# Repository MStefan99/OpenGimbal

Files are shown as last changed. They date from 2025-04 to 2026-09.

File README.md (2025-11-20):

# OpenGimbal

## Smooth footage made hackable

**Open source gimbal you can build, tweak and extend to match all your filming needs**

Note: OpenGimbal is undergoing final preparations before the first public release. Documentation is still being written
and hardware designs are undergoing final testing and will be published shortly.

## Highlights
### Hackable
Add as many motors as you like, control them over USB or UART and mount it anywhere you like. Use it as is or integrate it into your own project.

### Ready to use
Between firmware and software, PCB designs and 3D-printable parts, everything is ready for you to go.
Built-in calibrations and checks get the headache out of the setup process.

### Small but mighty
Film for 10 hours on a single charge, enjoy 15 watts of peak power and standby time measured in years.

## Introduction

A gimbal is a device that lets you shoot smooth video by canceling out unwanted camera movements. They come in many shapes and sizes, from tiny ones with integrated cameras to heavy-duty
devices for DSLRs or film cameras, often mounted on drones or cranes.

OpenGimbal can be all of those! The philosophy behind OpenGimbal is to make every single part customizable and extensible for your own needs.
The provided designs allow you to get started with a small but powerful smartphone gimbal in a few hours, but you can always adapt them to your own needs.

OpenGimbal is not just handy for gimbals, though. Grab included designs and firmware for brushless motor controllers and make anything you want move!

## Features

- Includes everything you need to get started: PCB designs, 3D models, firmware, software and documentation.
- Film for 10 hours on a single 18650 battery or add more capacity!
- Enjoy 15 watts of peak power with the provided controller or bring your own for up to 22 watts per motor!
- Stop worrying about the battery with USB-C charging and standby time measured in years.
- Every part can be customized, left out or replaced with your own designs to fit your needs.
- Can be easily controlled by your own software or hardware over USB or UART.
- Stock or custom, just point and shoot instantly without worrying about math with the fast IK solver.
- Easily customizable firmware with ready-made drivers, simple API and extensive documentation.
- Completely open source!

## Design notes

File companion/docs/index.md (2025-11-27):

---
# https://vitepress.dev/reference/default-theme-home-page
layout: home

hero:
  name: 'OpenGimbal'
  text: 'Smooth footage made hackable'
  tagline: Open source gimbal you can build, tweak and extend to match all your filming needs
  actions:
    - theme: brand
      text: Build your own
      link: /build
    - theme: alt
      text: Learn more
      link: /intro

features:
  - title: Hackable
    details: Add as many motors as you like, control them over USB or UART and mount it anywhere you want.
  - title: Butter smooth
    details: Don't let a stutter ruin your shot with refresh rates of up to 7000Hz
  - title: Lightning fast
    details: Shoot lag-free thanks to 4ms end-to-end latency and predictive oversampling
  - title: Small but mighty
    details: Film for 10 hours on a single charge, enjoy 15 watts of peak power and standby time measured in years.
---

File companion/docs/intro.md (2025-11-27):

# Introduction

::: warning
OpenGimbal is undergoing final preparations before the first public release. Documentation is still being written
and hardware designs are undergoing final testing and will be published shortly.
:::

A gimbal is a device that lets you shoot smooth video by canceling out unwanted camera movements. They come in many shapes and sizes, from tiny ones with integrated cameras to heavy-duty
devices for DSLRs or film cameras, often mounted on drones or cranes.

OpenGimbal can be all of those! The philosophy behind OpenGimbal is to make every single part customizable and extensible for your own needs.
The provided designs allow you to get started with a small but powerful smartphone gimbal in a few hours, but you can always adapt them to your own needs.

OpenGimbal is not just handy for gimbals, though. Grab included designs and firmware for brushless motor controllers and spin anything you want!

## Features

### Hackable

You can check out, customize, remove or replace every single part of the project to fit your needs.
Control the gimbal from your own hardware and software with simple API and provided libraries.

### Fast and smooth

Enjoy low latency and high refresh rates thanks to the firmware written for the best performance.

### Small but mighty

Film for 10 hours on a single 18650 battery or add more capacity. Instantly access 15 watts of peak power.
Charge over USB-C. Don't worry about battery with standby time measured in years.

### Math? Not needed

Use a blazing-fast IK solver for default configuration or go with numeric solver for custom designs.

### All-inclusive

Find everything you need to get started fast: PCB designs, 3D models, firmware, software, API, libraries and documentation.

### Completely open source!

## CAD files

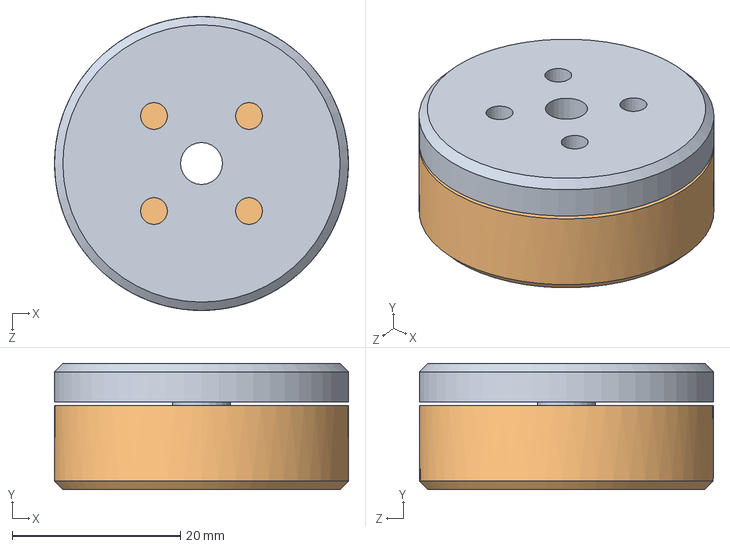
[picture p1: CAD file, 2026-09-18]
3D/Components/Motor.SLDASM
35.0 x 15.0 x 35.0 mm
Motor stator
Motor rotor

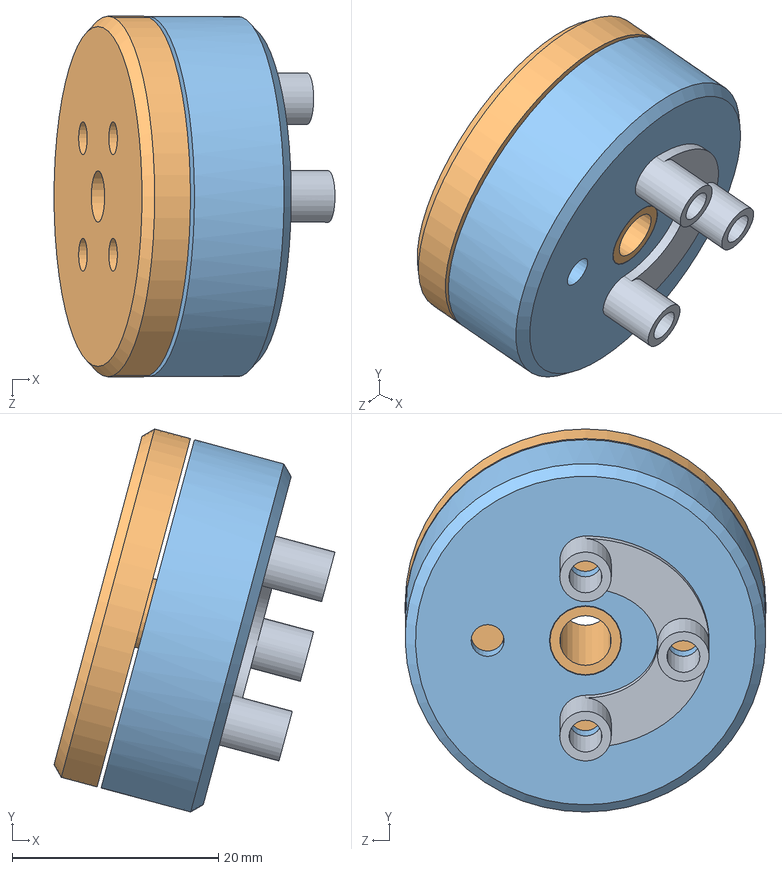
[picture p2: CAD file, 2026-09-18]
3D/Head/Motor assembly.SLDASM
27.3 x 37.2 x 35.0 mm
Motor stator
Motor rotor
Spacer

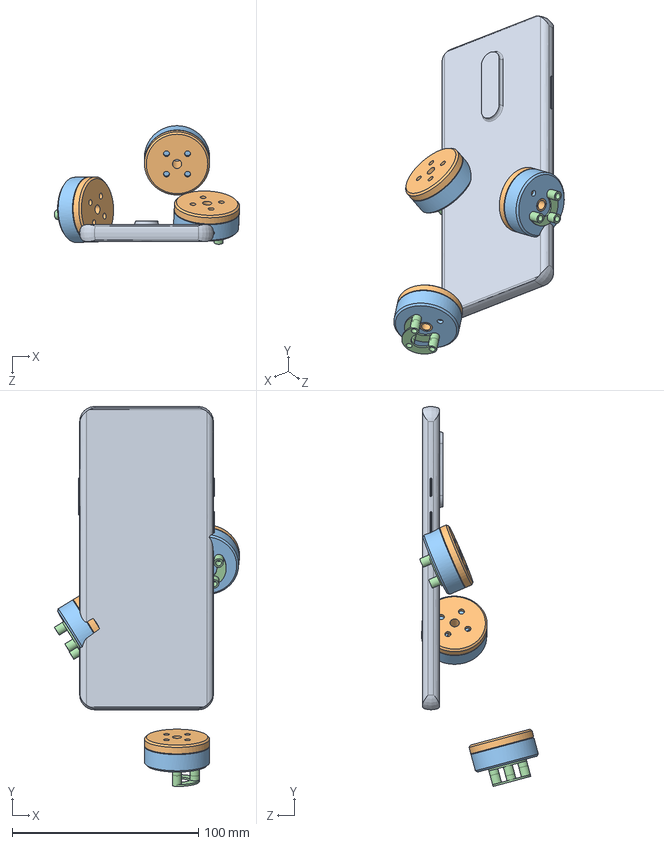
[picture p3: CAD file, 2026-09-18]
3D/Gimbal.SLDASM
99.4 x 203.9 x 63.7 mm
Spacer x 4
Motor stator x 3
Motor rotor x 3
Phone

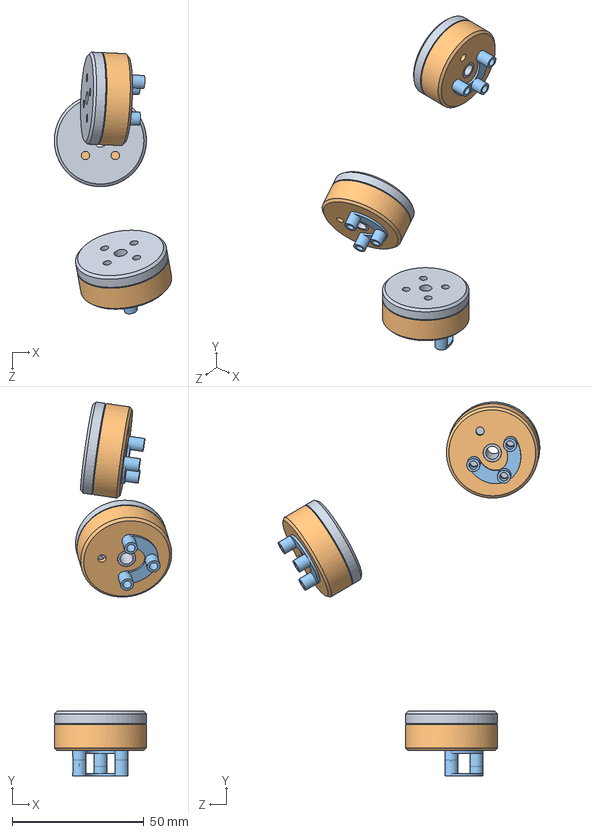
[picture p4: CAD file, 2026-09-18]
3D/Head/Head.SLDASM
44.6 x 142.0 x 99.4 mm
Spacer x 4
Motor stator x 3
Motor rotor x 3

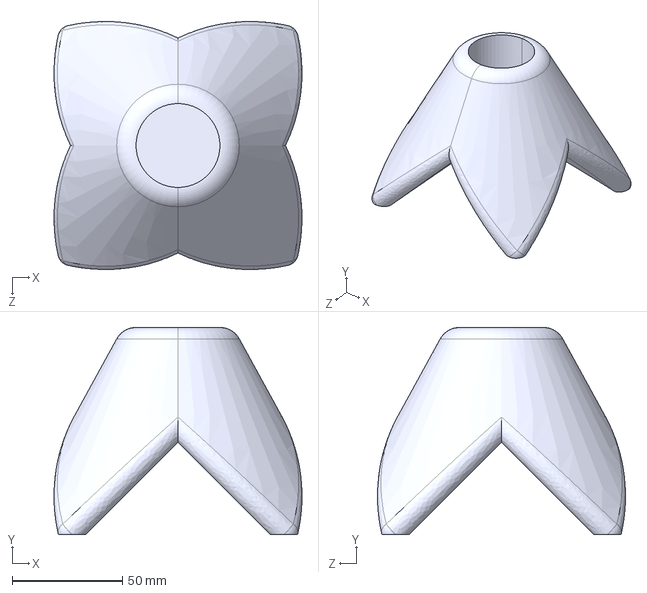
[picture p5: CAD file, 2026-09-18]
3D/Stand.STEP
112.3 x 93.9 x 112.3 mm

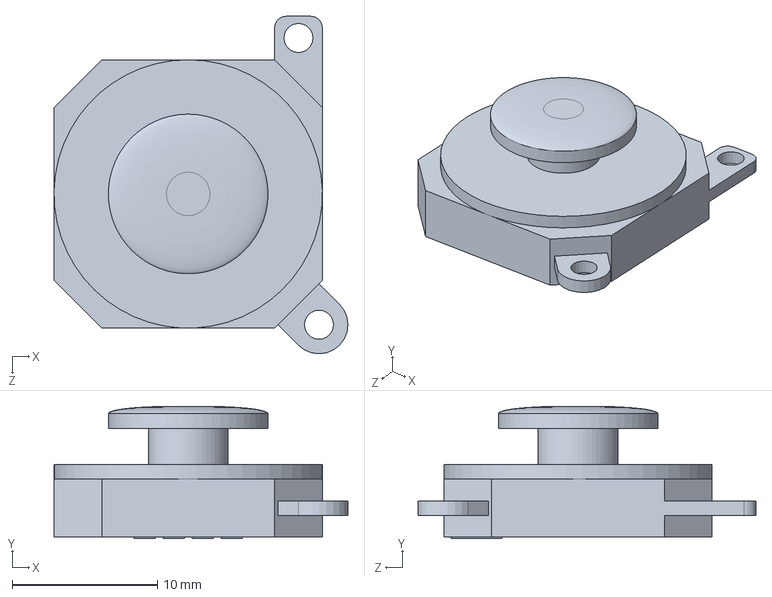
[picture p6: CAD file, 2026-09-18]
3D/Components/Joystick.SLDPRT
20.3 x 9.10 x 23.3 mm

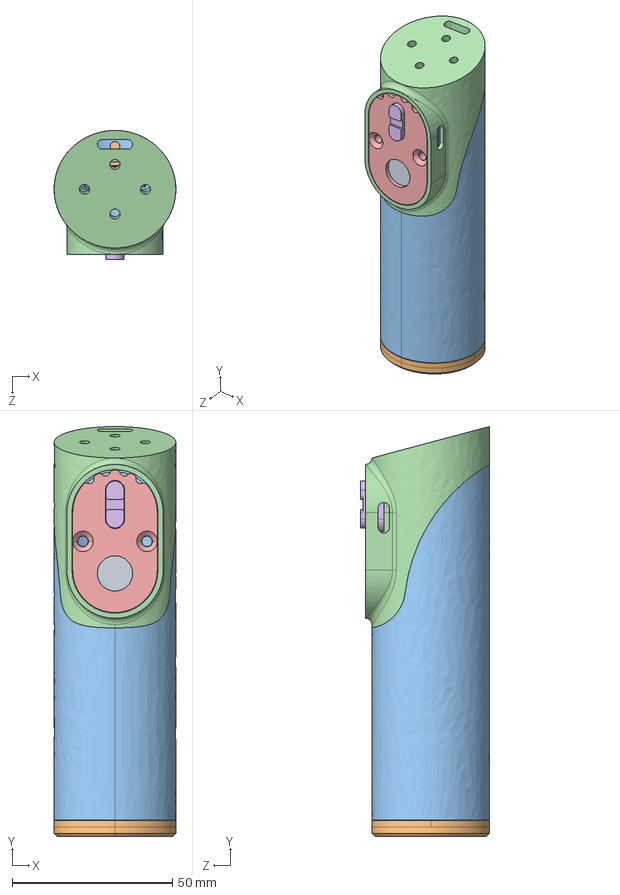
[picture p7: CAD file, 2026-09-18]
3D/Handle.STEP
38.0 x 127.9 x 40.3 mm

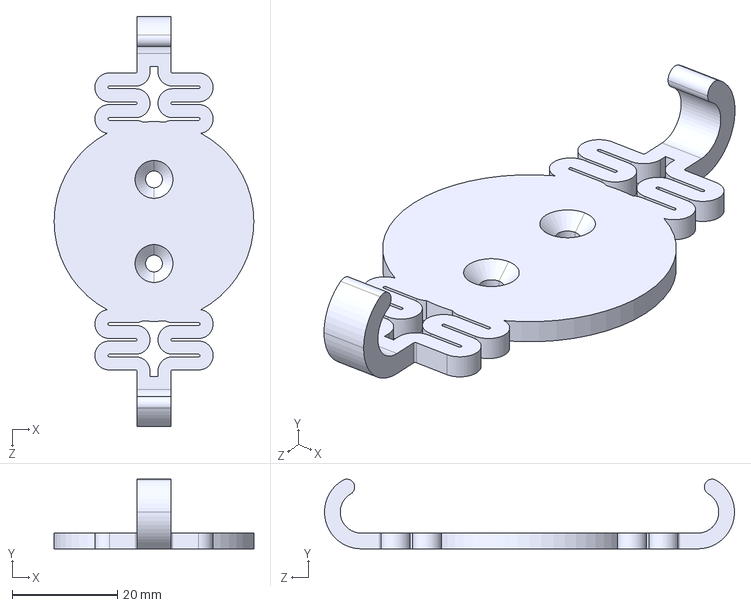
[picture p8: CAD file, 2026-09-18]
3D/Head/Phone spring clamp.STEP
38.0 x 13.3 x 78.0 mm

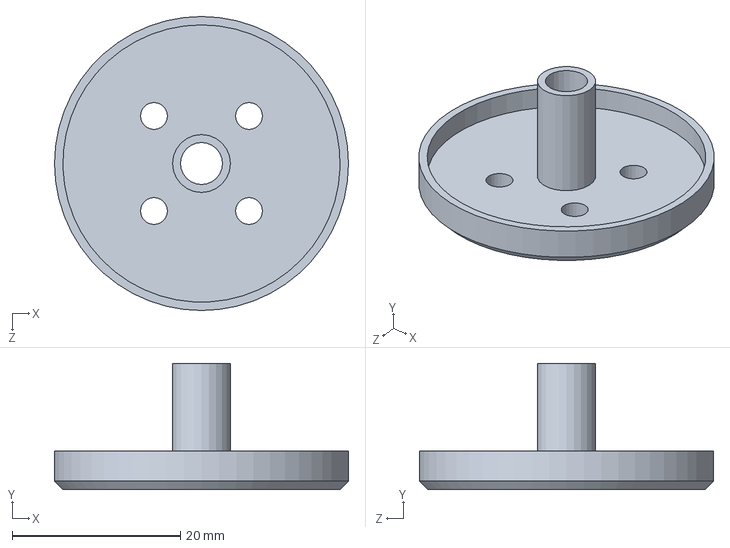
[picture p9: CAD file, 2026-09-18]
3D/Components/Motor rotor.SLDPRT
35.0 x 15.0 x 35.0 mm

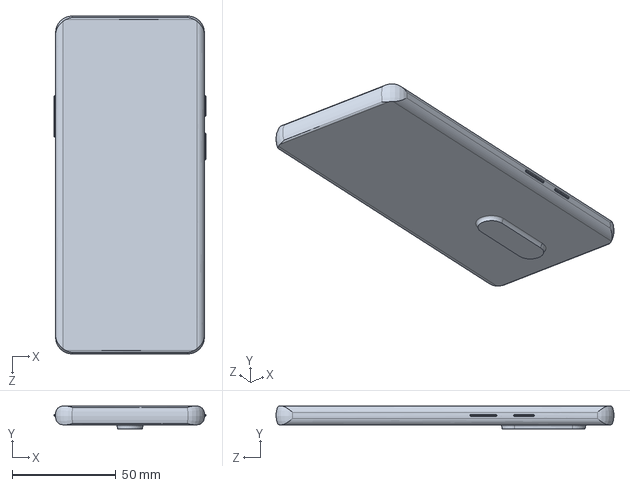
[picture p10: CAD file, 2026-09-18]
3D/Components/Phone.SLDPRT
73.0 x 11.0 x 162.7 mm

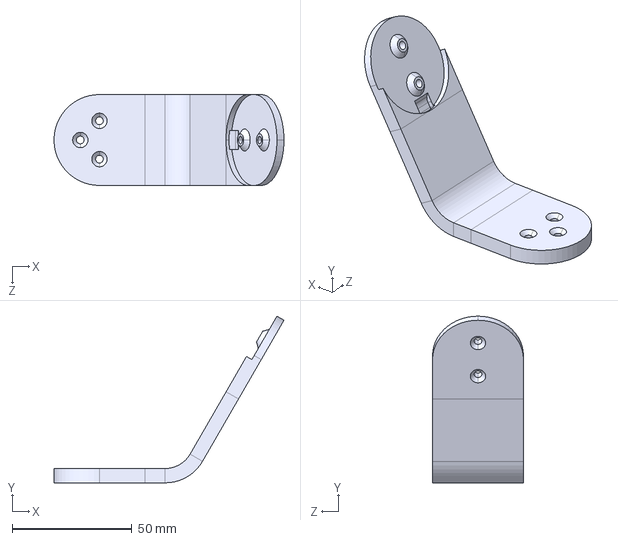
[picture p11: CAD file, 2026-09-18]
3D/Head/Lower arm.STEP
96.1 x 69.7 x 38.0 mm

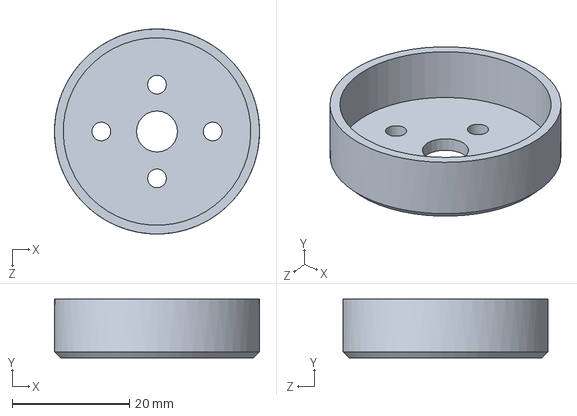
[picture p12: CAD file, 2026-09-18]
3D/Components/Motor stator.SLDPRT
35.0 x 10.0 x 35.0 mm

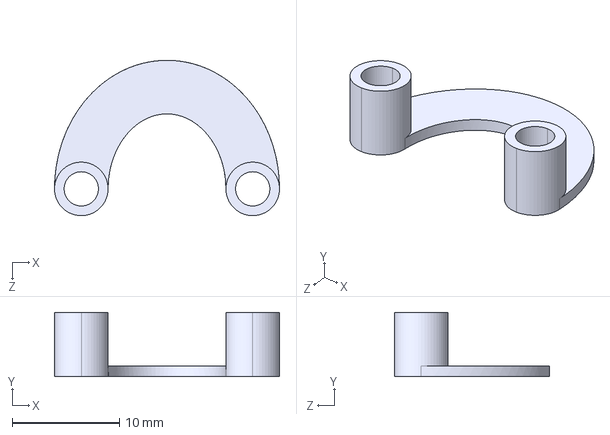
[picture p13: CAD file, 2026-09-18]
3D/Head/Top spacer.STEP
21.0 x 6.00 x 14.5 mm

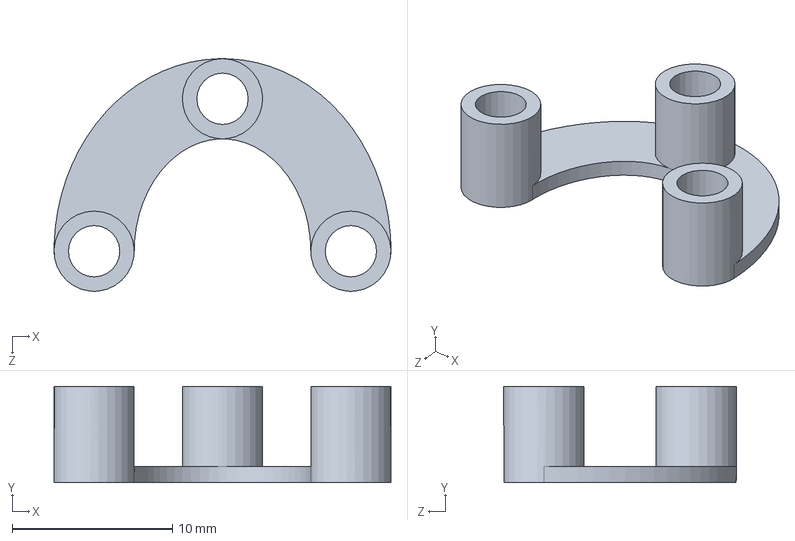
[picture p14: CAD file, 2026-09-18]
3D/Head/Spacer.SLDPRT
21.0 x 6.00 x 14.5 mm

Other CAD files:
3D/Head/Bottom spacer.STEP
3D/Head/Handle spacer.STEP
3D/Head/Motor cover.STEP
3D/Head/Upper arm.STEP
3D/Handle.DXF
3D/Handle.SLDPRT
3D/Head/Lower arm.SLDPRT
3D/Head/Motor cover upper.STEP
3D/Head/Motor cover.3MF
3D/Head/Motor cover.SLDPRT
3D/Head/Phone spring clamp.SLDPRT
3D/Head/Phone spring clamp.STL
3D/Head/Upper arm.SLDPRT
3D/Stand.SLDPRT

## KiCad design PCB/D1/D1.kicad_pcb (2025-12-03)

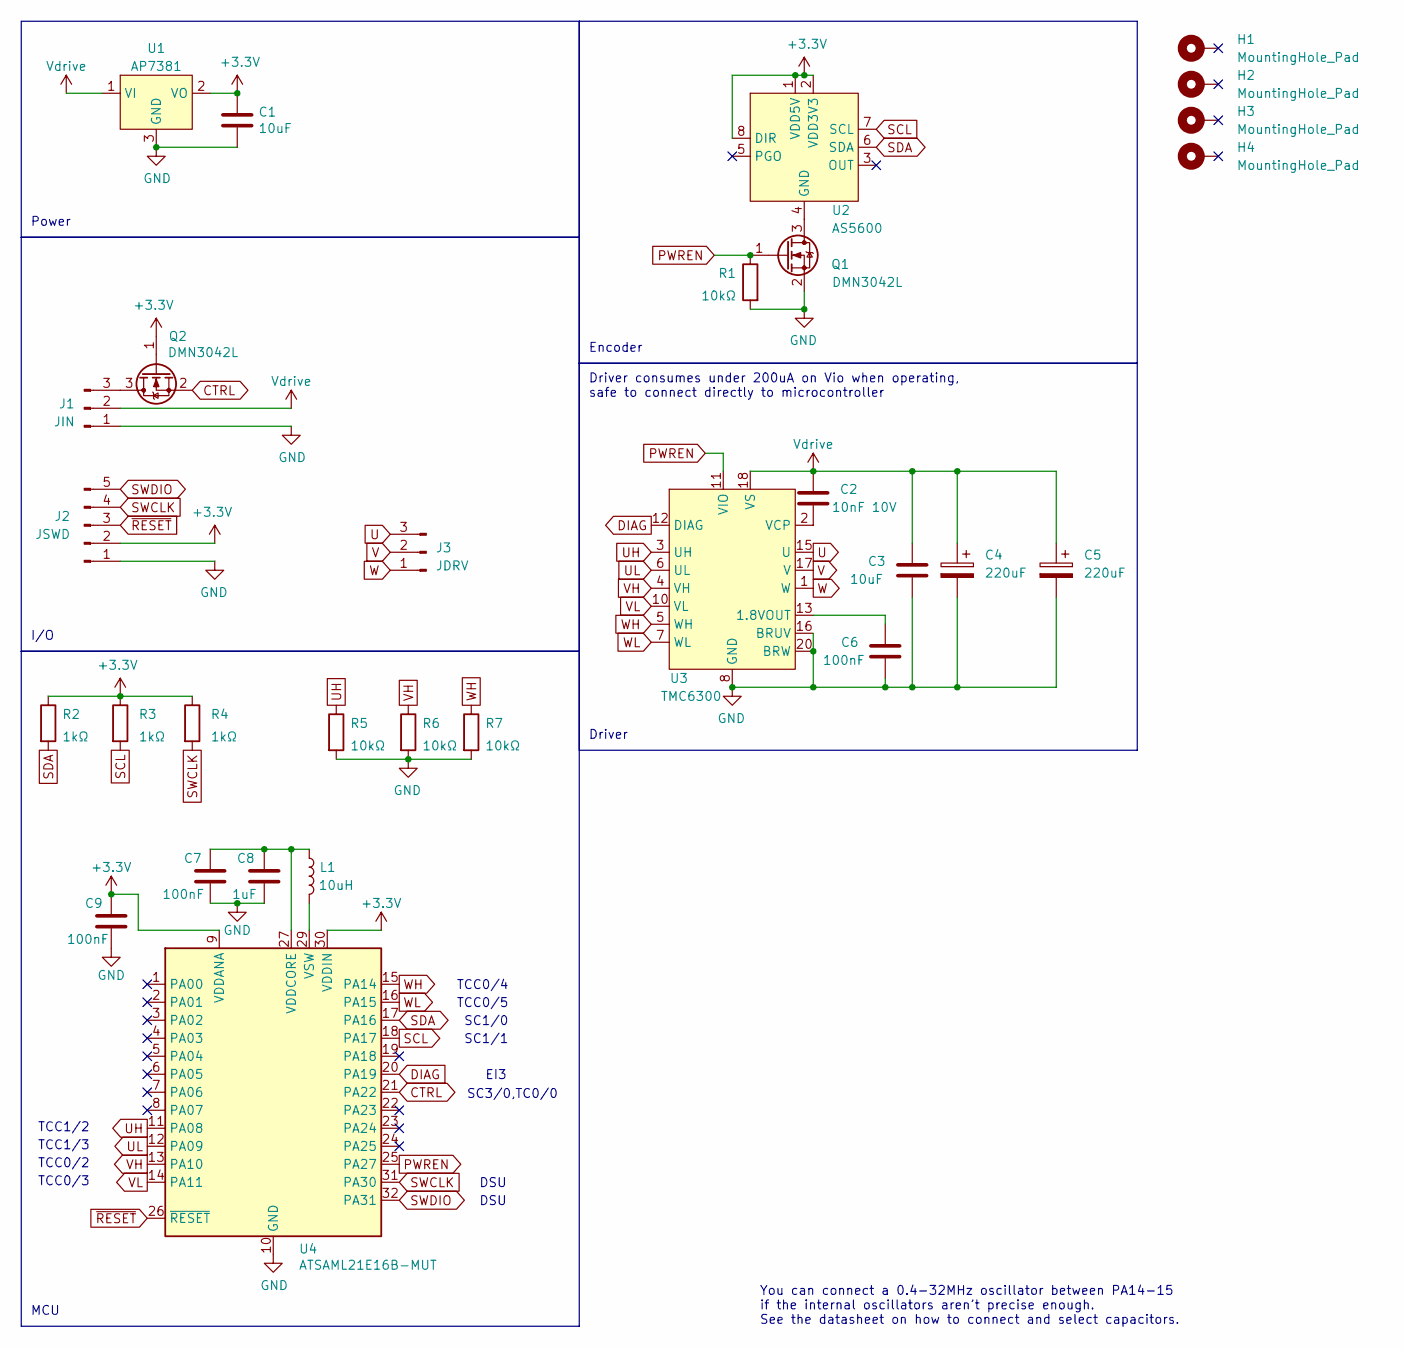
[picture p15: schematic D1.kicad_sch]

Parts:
C1, C3: 10uF; C_0603_1608Metric
C2: 10nF 10V; C_0603_1608Metric
C4, C5: 220uF; CP_EIA-7343-43_Kemet-X
C6, C7, C9: 100nF; C_0603_1608Metric
C8: 1uF; C_0603_1608Metric
H1, H2, H3, H4: MountingHole_Pad; MountingHole_3.2mm_M3_Pad
J1: JIN; PinHeader_1x03_P2.54mm_Vertical
J2: JSWD; PinHeader_1x05_P2.54mm_Vertical
J3: JDRV; PinHeader_1x03_P2.54mm_Vertical
L1: 10uH; C_0603_1608Metric
Q1, Q2: DMN3042L; SOT-23
R1, R5, R6, R7: 10kΩ; R_0603_1608Metric
R2, R3, R4: 1kΩ; R_0603_1608Metric
U1: AP7381; SOT-23
U2: AS5600; SOIC-8_3.9x4.9mm_P1.27mm
U3: TMC6300; QFN-20-1EP_3x3mm_P0.4mm_EP1.65x1.65mm
U4: ATSAML21E16B-MUT; QFN-32-1EP_5x5mm_P0.5mm_EP3.45x3.45mm

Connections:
+3.3V: C1.1, C9.1, J2.2, Q2.1 (G), R2.1, R3.1, R4.1, U1.2 (VO), U2.1 (VDD5V), U2.2 (VDD3V3), U2.8 (DIR), U4.9 (VDDANA), U4.30 (VDDIN)
CTRL: Q2.2 (S), U4.21 (PA22)
DIAG: U3.12 (DIAG), U4.20 (PA19)
GND: C1.2, C3.2, C4.2, C5.2, C6.2, C7.2, C8.2, C9.2, J1.1, J2.1, Q1.2 (S), R1.2, R5.2, R6.2, R7.2, U1.3 (GND), U3.8 (GND), U3.9 (GND), U3.14 (GND), U3.16 (BRUV), U3.20 (BRW), U3.21 (PAD), U4.10 (GND), U4.28 (GND), U4.33 (GND)
unnamed: J1.3, Q2.3 (D)
unnamed: Q1.3 (D), U2.4 (GND)
unnamed: C6.1, U3.13 (1.8VOUT)
unnamed: C2.2, U3.2 (VCP)
unnamed: C7.1, C8.1, L1.1, U4.27 (VDDCORE)
unnamed: L1.2, U4.29 (VSW)
PWREN: Q1.1 (G), R1.1, U3.11 (VIO), U4.25 (PA27)
SCL: R3.2, U2.7 (SCL), U4.18 (PA17)
SDA: R2.2, U2.6 (SDA), U4.17 (PA16)
SWCLK: J2.4, R4.2, U4.31 (PA30)
SWDIO: J2.5, U4.32 (PA31)
U: J3.3, U3.15 (U)
UH: R5.1, U3.3 (UH), U4.11 (PA08)
UL: U3.6 (UL), U4.12 (PA09)
V: J3.2, U3.17 (V)
VH: R6.1, U3.4 (VH), U4.13 (PA10)
VL: U3.10 (VL), U4.14 (PA11)
Vdrive: C2.1, C3.1, C4.1, C5.1, J1.2, U1.1 (VI), U3.18 (VS)
W: J3.1, U3.1 (W)
WH: R7.1, U3.5 (WH), U4.15 (PA14)
WL: U3.7 (WL), U4.16 (PA15)
~RESET: J2.3, U4.26 (~RESET)

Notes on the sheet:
Driver
SC1/0
TCC1/2
You can connect a 0.4-32MHz oscillator between PA14-15 if the internal oscillators aren't precise enough. See the datasheet on how to connect and select capacitors.
I/O
TCC0/3
Encoder
TCC1/3
DSU
TCC0/5
Power
Driver consumes under 200uA on Vio when operating, safe to connect directly to microcontroller
TCC0/4
SC1/1
SC3/0,TC0/0
MCU
TCC0/2
EI3

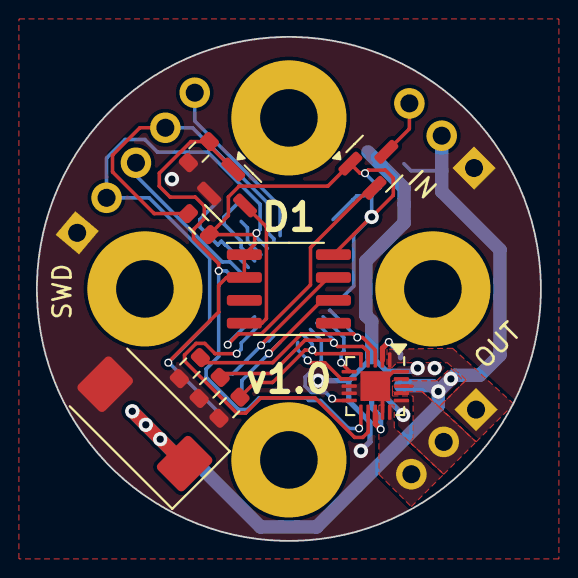
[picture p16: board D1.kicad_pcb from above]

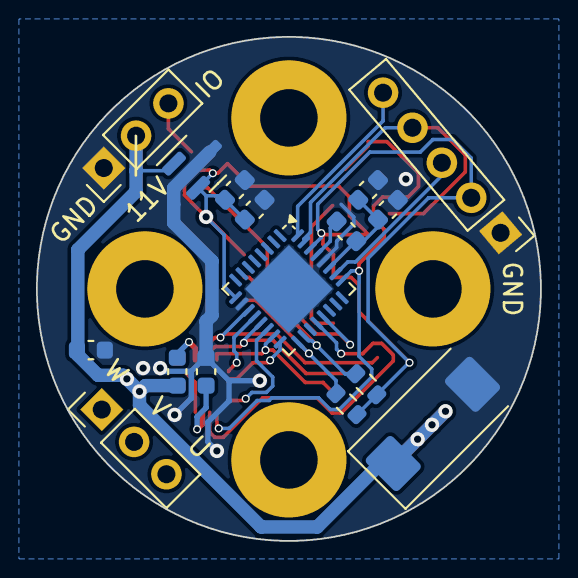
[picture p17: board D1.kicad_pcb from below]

Board: 2 copper layers, 28.0 x 28.0 mm, 30 parts (16 on the bottom side), 26 nets.

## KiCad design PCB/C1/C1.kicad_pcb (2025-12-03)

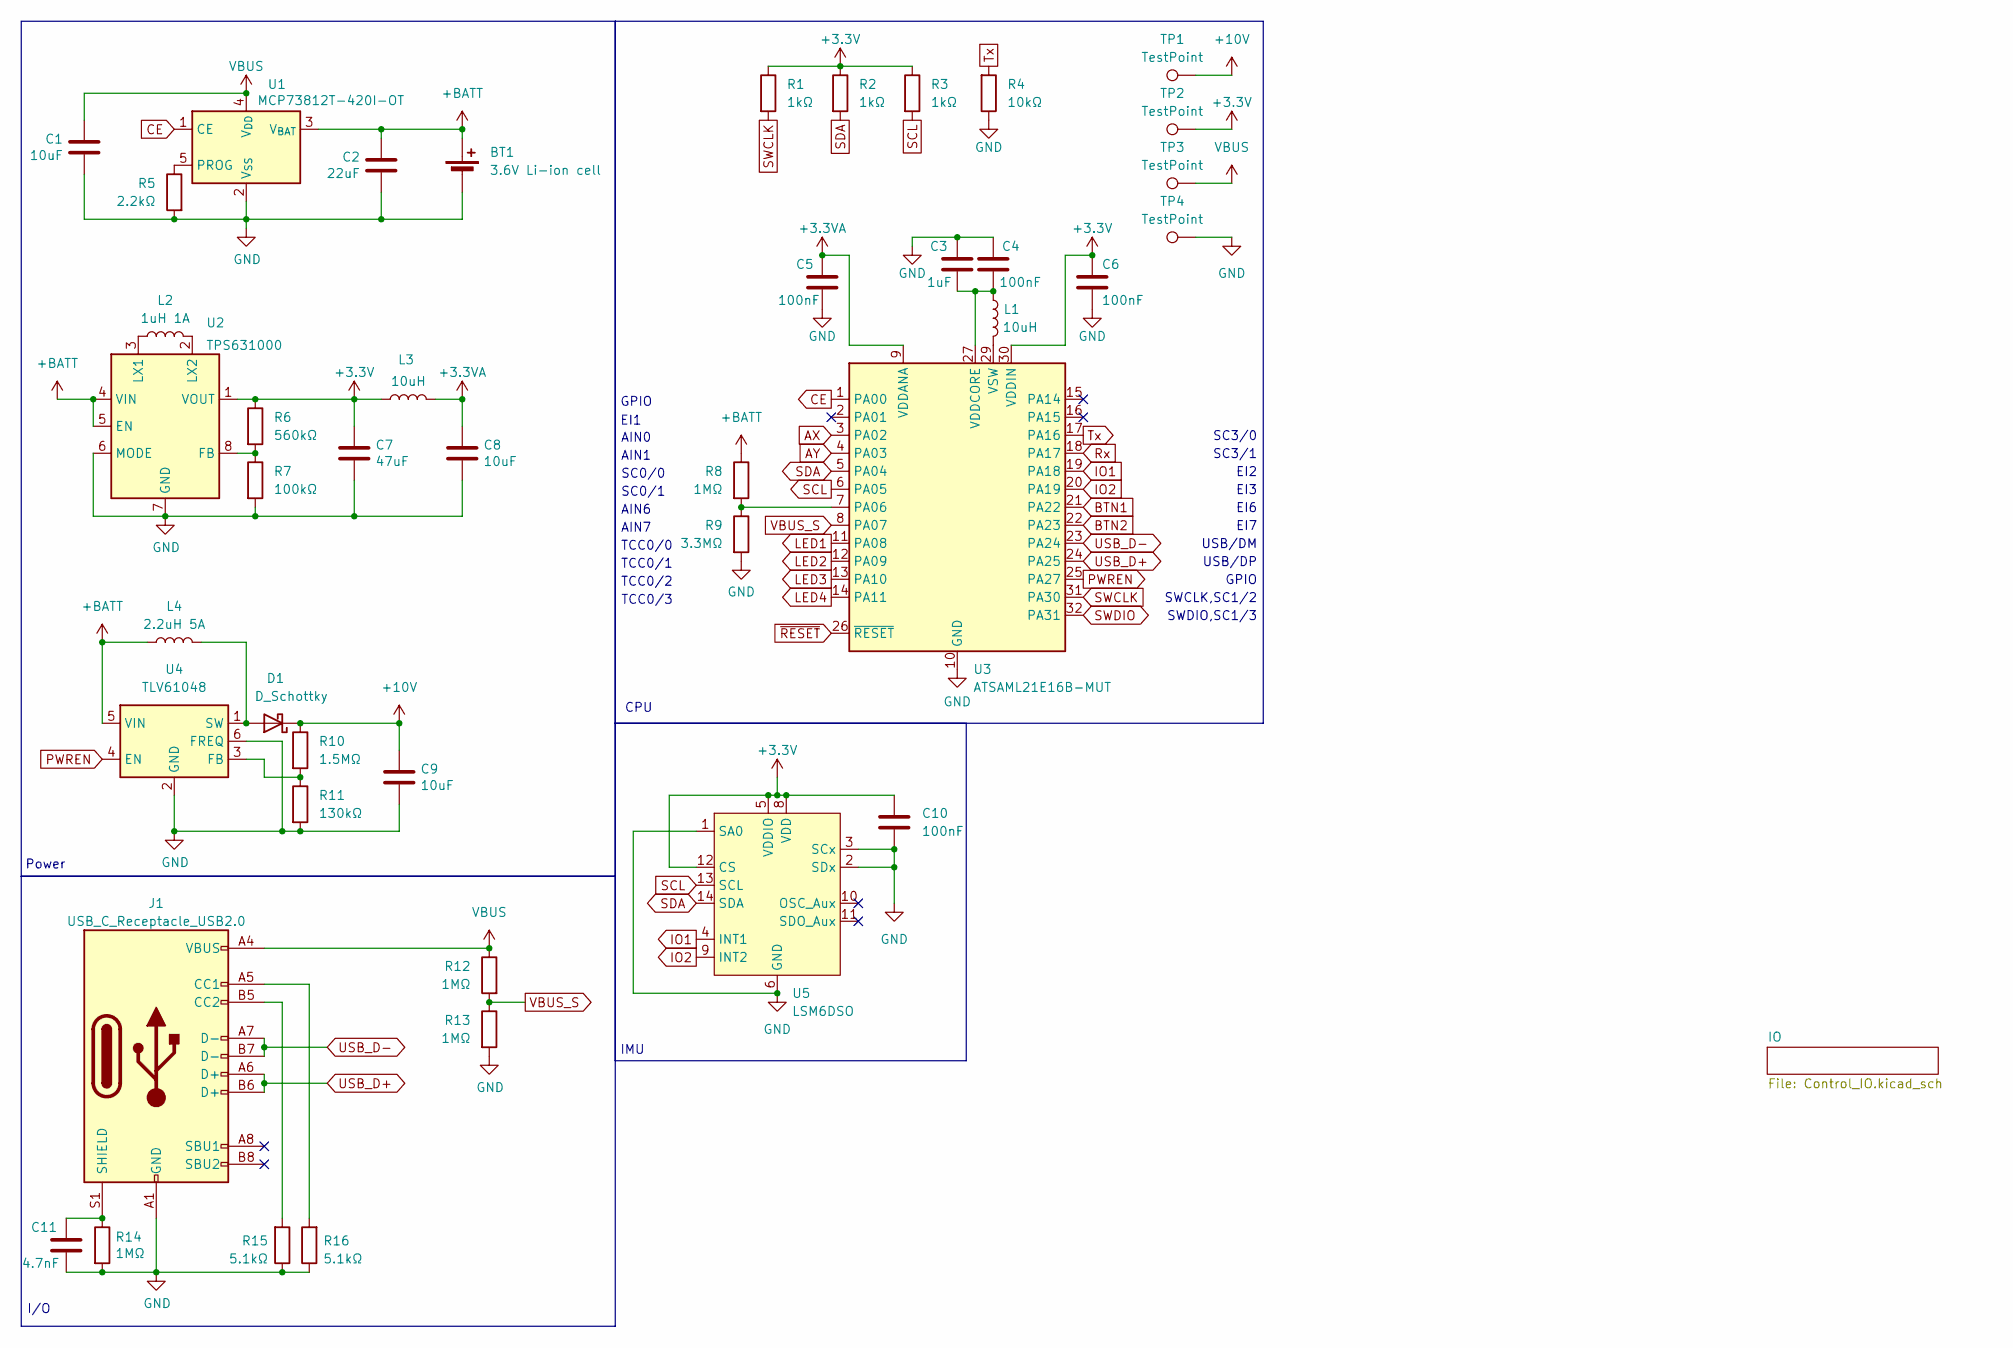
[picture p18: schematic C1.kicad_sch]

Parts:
BT1: 3.6V Li-ion cell; PinHeader_1x02_P2.54mm_Vertical
C1, C8, C9: 10uF; C_0603_1608Metric
C2: 22uF; C_0603_1608Metric
C3: 1uF; C_0603_1608Metric
C4, C5, C6, C10: 100nF; C_0603_1608Metric
C7: 47uF; C_0603_1608Metric
C11: 4.7nF; C_0603_1608Metric
D1: D_Schottky; D_SMA
J1: USB_C_Receptacle_USB2.0; USB4080
L1, L3: 10uH; C_0603_1608Metric
L2: 1uH 1A; L_0805_2012Metric
L4: 2.2uH 5A; L_TDK_VLS6045EX_VLS6045AF
R1, R2, R3: 1kΩ; R_0603_1608Metric
R4: 10kΩ; R_0603_1608Metric
R5: 2.2kΩ; R_0603_1608Metric
R6: 560kΩ; R_0603_1608Metric
R7: 100kΩ; R_0603_1608Metric
R8, R12, R13, R14: 1MΩ; R_0603_1608Metric
R9: 3.3MΩ; R_0603_1608Metric
R10: 1.5MΩ; R_0603_1608Metric
R11: 130kΩ; R_0603_1608Metric
R15, R16: 5.1kΩ; R_0603_1608Metric
TP1, TP2, TP3, TP4: TestPoint; TestPoint_Pad_D2.5mm
U1: MCP73812T-420I-OT; SOT-23-5
U2: TPS631000; SOT-583-8
U3: ATSAML21E16B-MUT; QFN-32-1EP_5x5mm_P0.5mm_EP3.45x3.45mm
U4: TLV61048; SOT-23-6
U5: LSM6DSO

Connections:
+3.3V: C6.1, C7.1, C10.2, L3.1, R1.1, R2.1, R3.1, R6.1, TP2.1, U2.1 (VOUT), U3.30 (VDDIN), U5.5 (VDDIO), U5.8 (VDD), U5.12 (CS); also elsewhere on the board
+3.3VA: C5.1, C8.1, L3.2, U3.9 (VDDANA)
+10V: C9.1, D1.1 (K), R10.1, TP1.1; also elsewhere on the board
+BATT: BT1.1 (+), C2.1, L4.1, R8.1, U1.3 (V_{BAT}), U2.4 (VIN), U2.5 (EN), U4.5 (VIN)
AX: U3.3 (PA02); also elsewhere on the board
AY: U3.4 (PA03); also elsewhere on the board
BTN1: U3.21 (PA22); also elsewhere on the board
BTN2: U3.22 (PA23); also elsewhere on the board
CE: U1.1 (CE), U3.1 (PA00)
GND: BT1.2 (-), C1.2, C2.2, C3.1, C4.1, C5.2, C6.2, C7.2, C8.2, C9.2, C10.1, C11.2, J1.A1 (GND), J1.A12 (GND), J1.B1 (GND), J1.B12 (GND), R4.1, R5.2, R7.2, R9.2, R11.2, R13.2, R14.2, R15.1, R16.1, TP4.1, U1.2 (V_{SS}), U2.6 (MODE), U2.7 (GND), U3.10 (GND), U3.28 (GND), U3.33 (GND), U4.2 (GND), U4.6 (FREQ), U5.1 (SA0), U5.2 (SDx), U5.3 (SCx), U5.6 (GND), U5.7 (GND); also elsewhere on the board
IO1: U3.19 (PA18), U5.4 (INT1)
IO2: U3.20 (PA19), U5.9 (INT2)
LED1: U3.11 (PA08); also elsewhere on the board
LED2: U3.12 (PA09); also elsewhere on the board
LED3: U3.13 (PA10); also elsewhere on the board
LED4: U3.14 (PA11); also elsewhere on the board
unnamed: D1.2 (A), L4.2, U4.1 (SW)
unnamed: J1.A5 (CC1), R16.2
unnamed: J1.B5 (CC2), R15.2
unnamed: C11.1, J1.S1 (SHIELD), R14.1
unnamed: R5.1, U1.5 (PROG)
unnamed: R6.2, R7.1, U2.8 (FB)
unnamed: L2.1, U2.3 (LX1)
unnamed: L2.2, U2.2 (LX2)
unnamed: R8.2, R9.1, U3.7 (PA06)
unnamed: C3.2, C4.2, L1.1, U3.27 (VDDCORE)
unnamed: L1.2, U3.29 (VSW)
unnamed: R10.2, R11.1, U4.3 (FB)
PWREN: U3.25 (PA27), U4.4 (EN); also elsewhere on the board
Rx: U3.18 (PA17); also elsewhere on the board
SCL: R3.2, U3.6 (PA05), U5.13 (SCL)
SDA: R2.2, U3.5 (PA04), U5.14 (SDA)
SWCLK: R1.2, U3.31 (PA30); also elsewhere on the board
SWDIO: U3.32 (PA31); also elsewhere on the board
Tx: R4.2, U3.17 (PA16); also elsewhere on the board
USB_D+: J1.A6 (D+), J1.B6 (D+), U3.24 (PA25)
USB_D-: J1.A7 (D-), J1.B7 (D-), U3.23 (PA24)
VBUS: C1.1, J1.A4 (VBUS), J1.A9 (VBUS), J1.B4 (VBUS), J1.B9 (VBUS), R12.1, TP3.1, U1.4 (V_{DD})
VBUS_S: R12.2, R13.1, U3.8 (PA07)
~RESET: U3.26 (~RESET); also elsewhere on the board

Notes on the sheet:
EI2
EI6
USB/DM
TCC0/1
SC0/1
AIN7
AIN6
SWDIO,SC1/3
EI3
AIN1
TCC0/3
GPIO
EI7
TCC0/0
IMU
USB/DP
EI1
TCC0/2
Power
AIN0
SC3/0
SC3/1
SWCLK,SC1/2
SC0/0
I/O
CPU

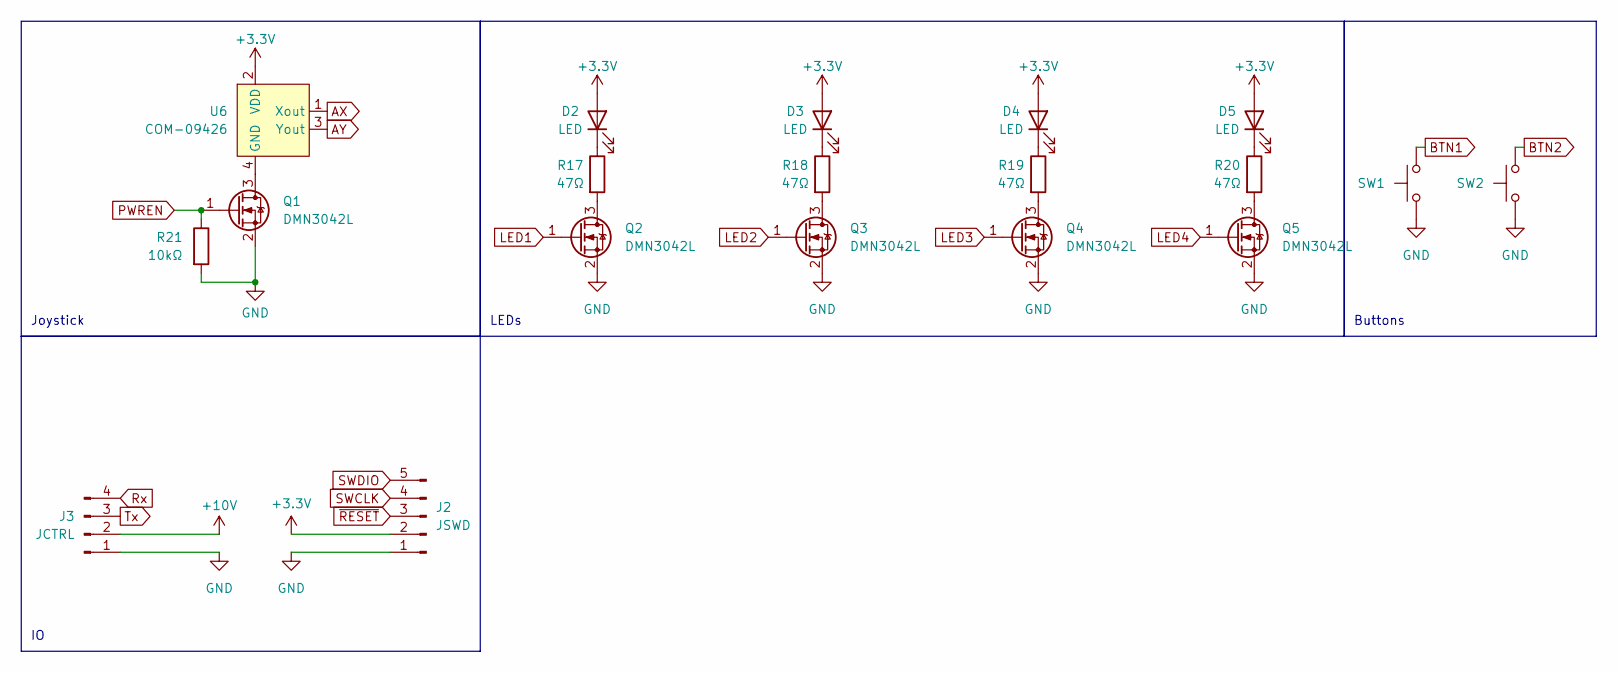
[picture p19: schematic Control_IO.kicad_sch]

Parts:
D2, D3, D4, D5: LED; D_0603_1608Metric
J2: JSWD; PinHeader_1x05_P2.54mm_Vertical
J3: JCTRL; PinHeader_1x04_P2.54mm_Vertical
Q1, Q2, Q3, Q4, Q5: DMN3042L; SOT-23
R17, R18, R19, R20: 47Ω; R_0603_1608Metric
R21: 10kΩ; R_0603_1608Metric
SW1, SW2: SW_Push; Switch
U6: COM-09426; COM-09426_NoHoles

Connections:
+3.3V: D2.2 (A), D3.2 (A), D4.2 (A), D5.2 (A), J2.2, U6.2 (VDD); also elsewhere on the board
+10V: J3.2; also elsewhere on the board
AX: U6.1 (Xout); also elsewhere on the board
AY: U6.3 (Yout); also elsewhere on the board
BTN1: SW1.2; also elsewhere on the board
BTN2: SW2.2; also elsewhere on the board
GND: J2.1, J3.1, Q1.2 (S), Q2.2 (S), Q3.2 (S), Q4.2 (S), Q5.2 (S), R21.2, SW1.1, SW2.1; also elsewhere on the board
LED1: Q2.1 (G); also elsewhere on the board
LED2: Q3.1 (G); also elsewhere on the board
LED3: Q4.1 (G); also elsewhere on the board
LED4: Q5.1 (G); also elsewhere on the board
unnamed: D2.1 (K), R17.1
unnamed: D3.1 (K), R18.1
unnamed: D4.1 (K), R19.1
unnamed: D5.1 (K), R20.1
unnamed: Q1.3 (D), U6.4 (GND)
unnamed: Q2.3 (D), R17.2
unnamed: Q3.3 (D), R18.2
unnamed: Q4.3 (D), R19.2
unnamed: Q5.3 (D), R20.2
PWREN: Q1.1 (G), R21.1; also elsewhere on the board
Rx: J3.4; also elsewhere on the board
SWCLK: J2.4; also elsewhere on the board
SWDIO: J2.5; also elsewhere on the board
Tx: J3.3; also elsewhere on the board
~RESET: J2.3; also elsewhere on the board

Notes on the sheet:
LEDs
Buttons
Joystick

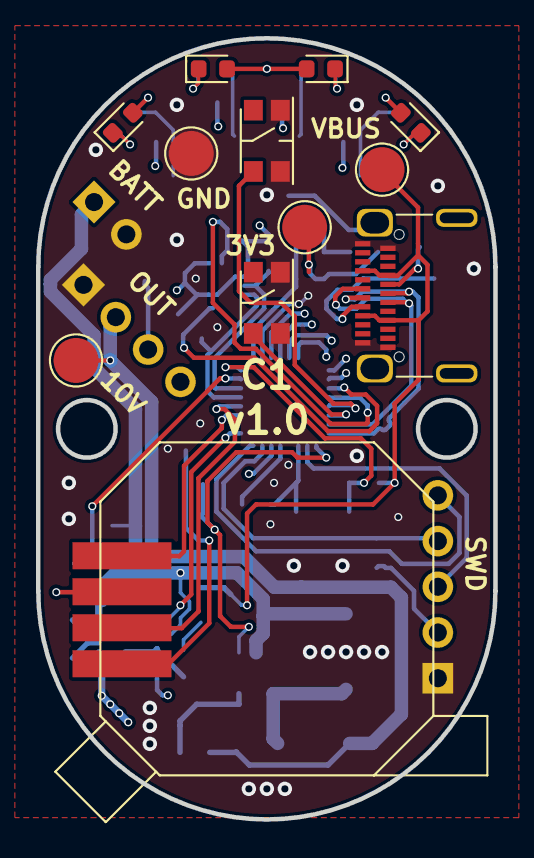
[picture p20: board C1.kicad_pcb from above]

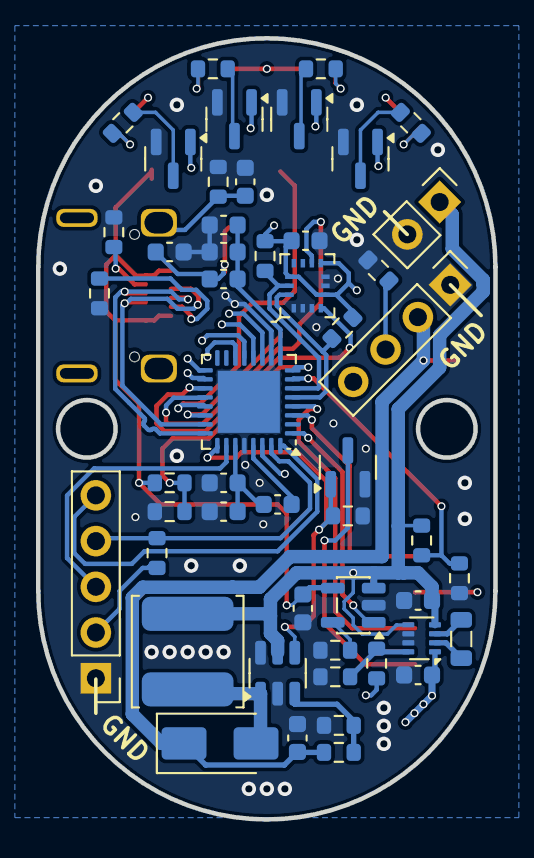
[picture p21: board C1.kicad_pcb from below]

Board: 4 copper layers, 25.4 x 43.4 mm, 62 parts (50 on the bottom side), 49 nets.

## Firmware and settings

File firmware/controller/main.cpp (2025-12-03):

#include "main.hpp"


volatile static DisplayState displayState {DisplayState::GimbalMode};
volatile static PowerMode    powerMode {PowerMode::Sleep};
volatile static GimbalMode   gimbalMode {GimbalMode::Follow};

constexpr static float    motorScalingFactor {2048 / F_PI};
constexpr static float    intScalingFactor {32768 / F_PI};
constexpr static float    ATT_LSB {10430.0f};
constexpr static float    joystickFactor {F_DEG_TO_RAD * (F_PI / 100.0f)};
constexpr static uint16_t deltaTime {1000 / updateRate};
constexpr static float    maxVelocityPerStep {maxRestoringVelocity / updateRate};

const static auto       controlBoardQuat {Quaternion::fromEuler(0, controlBoardAngle, 0)};
static Mahony           mahony {};
static AnalyticIKSolver ikSolver {};

volatile static bool sensorReady {false};
volatile static bool sensorDataReady {false};

volatile static uint8_t  motorPositionRequest {0};
volatile static uint32_t motorRequestTime {0};

static float          currentAngles[3] {0};
volatile static float offsetAngles[3] {0};
volatile static float resetAngles[3] {0};
volatile static float motorAngles[3] {0};

volatile static uint32_t softStartTime {0};
volatile static bool     softStartActive {false};

volatile static uint32_t stateChangeTime {0};
volatile static uint8_t  voltageBars {0};

volatile static uint8_t  shortPresses {0};
volatile static uint32_t eventTime {0};
volatile static bool     buttonPressed {false};
volatile static bool     primaryButton {true};

volatile static bool     motorPassthrough {false};
volatile static uint32_t motorPassthroughTime {0};

volatile static bool wokenByUSB {false};

float clampAngle(float difference) {
	if (difference > F_PI) {
		difference -= F_2_PI;
	} else if (difference < -F_PI) {
		difference += F_2_PI;
	}
	return difference;
}

void setLEDs(uint32_t brightnesses) {
	for (uint8_t i {0}; i < 4; ++i) {
		pwm::setBrightness(i, brightnesses << 8u);
		brightnesses >>= 8u;
	}
}

void showMode() {
	if (powerMode == PowerMode::Idle || powerMode == PowerMode::Sleep) {
		setLEDs(0);
	} else {
		setLEDs(0xff << static_cast<uint8_t>(gimbalMode) * 8);
	}
}

void showBattery(uint16_t value) {
	setLEDs(0);
	stateChangeTime = util::getTime();
	displayState = DisplayState::BatteryLevel;
	voltageBars = util::scale(
	                  util::clamp(value, MIN_VOLTAGE, MAX_VOLTAGE),
	                  MIN_VOLTAGE,
	                  MAX_VOLTAGE,
	                  static_cast<uint16_t>(0),
	                  static_cast<uint16_t>(65535)
	              ) / (65535 / 8)
	            + 1;
}

void enable() {
	adc::measureBattery([](uint16_t value) {
		if (value > MIN_VOLTAGE) {
			uart::enable();
			displayState = DisplayState::GimbalMode;
			PORT_REGS->GROUP[0].PORT_OUTSET = 0x1 << 27u;
			joystick::updateCenter();
			LSM6DSO32::enable();
			powerMode = PowerMode::Active;

			softStartActive = true;
			softStartTime = util::getTime();

			motor::wake();
			motor::tone();  // In case tone was previously set
			motorPositionRequest = 0;
			motorRequestTime = util::getTime();
			showMode();

			WDT_REGS->WDT_CTRLA = WDT_CTRLA_ENABLE(1);
		} else {
			showBattery(value);
		}
	});
}

void disable() {
	powerMode = PowerMode::Sleep;
	PORT_REGS->GROUP[0].PORT_OUTCLR = 0x1 << 27u;
	joystick::saveValues();
	offsetAngles[0] = offsetAngles[1] = offsetAngles[2] = resetAngles[0] = resetAngles[2] = 0;
	LSM6DSO32::disable();
	showMode();
}

void sendToHost(const uint8_t* buffer, uint8_t len) {
	uint8_t buf[len + 1];
	buf[0] = len;
	util::copy(buf + 1, buffer, len);

	host::send(buf, len + 1);
	usb::write(buf + 1, len);
}

// CAUTION: This function is called in an interrupt, no long-running operations allowed here!
void processMotorMessage(const uart::DefaultCallback::buffer_type& buffer) {
	if (motorPassthrough) {
		uint8_t buf[20];
		buf[0] = static_cast<uint8_t>(HostResponse::ResponseType::MotorPassthrough);
		util::copy(buf + 1, buffer.buffer, buffer.transferred);

		sendToHost(buf, buffer.transferred + 1);

		motorPassthrough = false;
		return;
	}

	if ((buffer.buffer[0] & 0xf) != 0) {
		return;  // Command intended for another device
	}

	uint8_t srcAddress = (buffer.buffer[1] >> 4u);
	if (static_cast<MotorResponse::ResponseType>(buffer.buffer[1] & 0xf) == MotorResponse::ResponseType::ReturnVariable
	    && static_cast<MotorResponse::Variable>(buffer.buffer[2]) == MotorResponse::Variable::Position
	    && srcAddress < 4) {
		float angle = static_cast<uint16_t>(((buffer.buffer[3] & 0xf) << 8u) | buffer.buffer[4]) / motorScalingFactor;
		motorAngles[srcAddress - 1] = angle;
	}
}

// CAUTION: This function is called in an interrupt, no long-running operations allowed here!
void processHostCommand(const uint8_t* buf, uint8_t len) {
	switch (static_cast<HostCommand::CommandType>(buf[0])) {
		case (HostCommand::CommandType::Sleep): {
			disable();
			break;
		}
		case (HostCommand::CommandType::Wake): {
			enable();
			break;
		}
		case (HostCommand::CommandType::Discovery): {
			auto response = HostResponse {HostResponse::ResponseType::Discovery, 0};
			sendToHost(response.getBuffer(), response.getLength());
			break;
		}
		case (HostCommand::CommandType::GetVariable): {
			switch (static_cast<HostCommand::Variable>(buf[1])) {
				case (HostCommand::Variable::Orientation): {
					int16_t data[3];
					for (uint8_t i {0}; i < 3; ++i) {
						data[i] = __REV16(static_cast<int16_t>(offsetAngles[i] * intScalingFactor));
					}

					auto response = HostReturnVariableResponse {
					  HostResponse::Variable::Orientation,
					  reinterpret_cast<uint8_t*>(data),
					  sizeof(data)
					};
					sendToHost(response.getBuffer(), response.getLength());
					break;
				}
				case (HostCommand::Variable::HandleOrientation): {
					int16_t    data[3];
					Quaternion handleOrientation {mahony.getQuat() * controlBoardQuat};
					auto       handleAngles {handleOrientation.toEuler()};

					for (uint8_t i {0}; i < 3; ++i) {
						data[i] = __REV16(static_cast<int16_t>(handleAngles[i][0] * intScalingFactor));
					}

					auto response = HostReturnVariableResponse {
					  HostResponse::Variable::HandleOrientation,
					  reinterpret_cast<uint8_t*>(data),
					  sizeof(data)
					};
					sendToHost(response.getBuffer(), response.getLength());
					break;
				}
				case (HostCommand::Variable::Mode): {
					auto response = HostReturnVariableResponse {HostResponse::Variable::Mode, static_cast<uint8_t>(gimbalMode)};
					sendToHost(response.getBuffer(), response.getLength());
					break;
				}
				case (HostCommand::Variable::BatteryVoltage): {
					adc::measureBattery([](uint16_t value) {
						uint8_t voltage = util::scale(
						    util::clamp(value, MIN_VOLTAGE, MAX_VOLTAGE),
						    MIN_VOLTAGE,
						    MAX_VOLTAGE,
						    static_cast<uint16_t>(0),
						    static_cast<uint16_t>(255)
						);

						auto response = HostReturnVariableResponse {HostResponse::Variable::BatteryVoltage, voltage};
						sendToHost(response.getBuffer(), response.getLength());
					});
					break;
				}
				case (HostCommand::Variable::DeviceVersion): {
					auto response =
					    HostReturnVariableResponse {HostResponse::Variable::DeviceVersion, usb::DESCRIPTOR_DEVICE.bcdDevice};
					sendToHost(response.getBuffer(), response.getLength());
					break;
				}
				case (HostCommand::Variable::VendorName): {
					auto response = HostReturnVariableResponse {
					  HostResponse::Variable::VendorName,
					  reinterpret_cast<uint8_t*>(usb::DESCRIPTOR_STRING[1].bString),
					  static_cast<uint8_t>(usb::DESCRIPTOR_STRING[1].bLength - 2)
					};
					sendToHost(response.getBuffer(), response.getLength());
					break;
				}
				case (HostCommand::Variable::ProductName): {
					auto response = HostReturnVariableResponse {
					  HostResponse::Variable::ProductName,
					  reinterpret_cast<uint8_t*>(usb::DESCRIPTOR_STRING[2].bString),
					  static_cast<uint8_t>(usb::DESCRIPTOR_STRING[2].bLength - 2)
					};
					sendToHost(response.getBuffer(), response.getLength());
					break;
				}
				case (HostCommand::Variable::SerialNumber): {
					auto response = HostReturnVariableResponse {
					  HostResponse::Variable::SerialNumber,
					  reinterpret_cast<uint8_t*>(usb::DESCRIPTOR_STRING[3].bString),
					  static_cast<uint8_t>(usb::DESCRIPTOR_STRING[3].bLength - 2)
					};
					sendToHost(response.getBuffer(), response.getLength());
					break;
				}
				default:
					break;
			}
			break;
		}
		case (HostCommand::CommandType::SetVariable): {
			switch (static_cast<HostCommand::Variable>(buf[1])) {
				case (HostCommand::Variable::Orientation): {
					for (uint8_t i {0}; i < 3; ++i) {
						offsetAngles[i] =
						    static_cast<int16_t>(__REV16(reinterpret_cast<const int16_t*>(buf + 2)[i])) / intScalingFactor;
					}
					break;
				}
				case (HostCommand::Variable::Mode): {
					gimbalMode = static_cast<GimbalMode>(util::min(buf[2], static_cast<uint8_t>(4)));
					showMode();
					break;
				}
				default:
					break;
			}
			break;
		}
		case (HostCommand::CommandType::MotorPassthrough): {
			motorPassthrough = true;
			motorPassthroughTime = util::getTime();
			motor::send(buf + 1, len - 1);
			break;
		}
		default:
			break;
	}
}

void processHostMessage(const host::DefaultCallback::buffer_type& buffer) {
	uint8_t buf[buffer.transferred - 1];
	util::copy(buf, buffer.buffer + 1, buffer.transferred - 1);  // Avoids unaligned access

	processHostCommand(buf, buffer.transferred - 1);
}

// CAUTION: This function is called in an interrupt, no long-running operations allowed here!
void processUSBMessage(const usb::usb_device_endpoint1_request& request, uint16_t len) {
	processHostCommand(&request.bRequest, len);
}

// CAUTION: This function is called in an interrupt, no long-running operations allowed here!
void processSensor() {
	sensorReady = true;
}

// CAUTION: This function is called in an interrupt, no long-running operations allowed here!
void processButtons(bool primary, bool pressed) {
	if (pressed) {
		if (powerMode == PowerMode::Sleep) {
			powerMode = PowerMode::Idle;
		} else if (displayState == DisplayState::BatteryLevel) {
			displayState = DisplayState::GimbalMode;
			showMode();
		}
	} else if (util::getTime() - eventTime < MAX_PRESS_WAIT_TIME) {
		++shortPresses;
	}

	eventTime = util::getTime();
	buttonPressed = pressed;
	primaryButton = primary;

	if (powerMode == PowerMode::Idle) {
		if (!buttonPressed) {
			showMode();
		} else {
			setLEDs(0xffffffff);
		}
	} else if (displayState == DisplayState::GimbalMode) {
		if (!buttonPressed) {
			showMode();
		} else {
			setLEDs(0);
		}
	}
}

bool triggerAction() {
	bool isOff {powerMode != PowerMode::Active};

	if (buttonPressed) {  // buttonPressed being true means this is a long press
		if (shortPresses == 1) {
			uint8_t led = (util::getTime() - (eventTime + MAX_SHORT_PRESS_TIME)) / LONG_PRESS_STEP_TIME;
			pwm::setBrightness(led - 1, isOff ? 0xffff : 0);

			if (!led) {
				setLEDs(isOff ? 0 : 0xffffffff);
			} else if (led > 3) {
				if (isOff) {
					enable();
				} else {
					disable();
				}
				showMode();

				return true;
			}
		} else if (shortPresses == 3) {
			__NVIC_SystemReset();
		} else {
			return true;
		}
	} else if (shortPresses == 1 && (!primaryButton || isOff)) {
		adc::measureBattery([](uint16_t value) {
			if (powerMode == PowerMode::Sleep) {
				powerMode = PowerMode::Idle;
			}

			showBattery(value);
		});
	} else if (!isOff) {
		if (primaryButton) {
			if (shortPresses == 1) {
				offsetAngles[0] = resetAngles[0];
				offsetAngles[1] = 0;
				offsetAngles[2] = resetAngles[2];
			} else if (shortPresses == 2) {
				resetAngles[2] += F_PI_2;
				if (resetAngles[2] > F_PI + 0.05f) {
					resetAngles[2] = 0;
				}
				offsetAngles[2] = resetAngles[2];
			} else if (shortPresses == 3) {
				resetAngles[0] += F_PI;
				if (resetAngles[0] > F_PI + 0.05f) {
					resetAngles[0] = 0;
				}
				offsetAngles[0] = resetAngles[0];
			}
		} else {
			if (shortPresses == 2) {
				if (gimbalMode == GimbalMode::Tilt) {
					gimbalMode = GimbalMode::Horizon;
				} else {
					gimbalMode = static_cast<GimbalMode>(static_cast<uint8_t>(gimbalMode) + 1);
				}
				showMode();
			}
		}
	} else if (powerMode == PowerMode::Idle) {
		powerMode = PowerMode::Sleep;
	}

	return !buttonPressed;
}

void sleep() {
	WDT_REGS->WDT_CTRLA = WDT_CTRLA_ENABLE(0);
	while (uart::busy() || host::busy() || i2c::busy()) {
		__WFI();
	}
	uart::disable();
	host::disable();
	PM_REGS->PM_SLEEPCFG = PM_SLEEPCFG_SLEEPMODE_STANDBY;
	while (PM_REGS->PM_SLEEPCFG != PM_SLEEPCFG_SLEEPMODE_STANDBY);
	do {
		__WFI();
	} while (powerMode == PowerMode::Sleep && !usb::isActive());
	PM_REGS->PM_SLEEPCFG = PM_SLEEPCFG_SLEEPMODE_IDLE;
	while (PM_REGS->PM_SLEEPCFG != PM_SLEEPCFG_SLEEPMODE_IDLE);
}

int main() {
	util::init();
	eic::init();
	adc::init();
	pwm::init();
	i2c::init();
	uart::init();
	host::init();
	usb::init();

	eic::setButtonCallback(processButtons);
	eic::setSensor1Callback(processSensor);
	eic::setHostCallback([]() {
		host::enable();
	});
	uart::setCallback(processMotorMessage);
	host::setCallback(processHostMessage);
	usb::setCallback(processUSBMessage);

	PORT_REGS->GROUP[0].PORT_DIRSET = 0x1 | (0x1 << 27u);
	PORT_REGS->GROUP[0].PORT_OUTSET = 0x1;  // Charging always enabled for now

	WDT_REGS->WDT_CONFIG = WDT_CONFIG_PER_CYC64;

	usb::setSuspendCallback([](bool suspended) {
		if (suspended) {
			powerMode = PowerMode::Idle;
			disable();
		} else {
			uart::enable();
			wokenByUSB = true;
		}
	});

	{
		uint8_t steps {150};

		for (uint8_t step {0}; step < steps; ++step) {
			auto percentage = util::scale(static_cast<int>(step), 0, static_cast<int>(steps), 0, 255);
			auto brightnessInner = util::clamp(util::min(percentage, 192 - percentage), 0, 192) * (65535 / 192);
			auto brightnessOuter = util::clamp(util::min(percentage - 63, 255 - percentage), 0, 192) * (65535 / 192);

			pwm::setBrightness(1, brightnessInner);
			pwm::setBrightness(2, brightnessInner);

			pwm::setBrightness(0, brightnessOuter);
			pwm::setBrightness(3, brightnessOuter);

			util::sleep(1000 / steps);
		}
		setLEDs(0);
	}

	while (1) {
		switch (powerMode) {
			case (PowerMode::Active): {
				auto startTime {util::getTime()};

				LSM6DSO32::update([]() {
					sensorDataReady = true;
				});

				while (!sensorDataReady && util::getTime() - startTime < deltaTime / 4) {
					__WFI();
				}
				sensorDataReady = false;

				mahony.updateIMU(LSM6DSO32::getAngularRates(), LSM6DSO32::getAccelerations(), deltaTime / 1000.0f);

				joystick::update([](int16_t x, int16_t y) {
					if (gimbalMode != GimbalMode::Tilt) {
						offsetAngles[0] -= y / 40000.0f;
					} else {
						offsetAngles[2] -= y / 40000.0f;
					}
					offsetAngles[1] += x / 40000.0f;

					for (uint8_t i {0}; i < 3; ++i) {
						offsetAngles[i] = clampAngle(offsetAngles[i]);
					}
				});

				Quaternion handleOrientation {mahony.getQuat() * controlBoardQuat};
				auto       handleAngles {handleOrientation.toEuler()};

				float yawTarget {handleAngles[0][0] + offsetAngles[0]};

				float sy {sinf(offsetAngles[0])};
				float cy {cosf(offsetAngles[0])};

				float pitchTarget {
				  (gimbalMode == GimbalMode::Horizon ? 0 : cy * handleAngles[1][0] - sy * handleAngles[2][0]) + offsetAngles[1]
				};
				float rollTarget {
				  (gimbalMode <= GimbalMode::Follow ? 0 : cy * handleAngles[2][0] + sy * handleAngles[1][0]) - offsetAngles[2]
				};

				for (uint8_t i {0}; i < 3; ++i) {
					currentAngles[i] = clampAngle(currentAngles[i]);
				}

				currentAngles[0] +=
				    util::clamp(clampAngle(yawTarget - currentAngles[0]) / 50.0f, -maxVelocityPerStep, maxVelocityPerStep);

				currentAngles[1] +=
				    util::clamp(clampAngle(pitchTarget - currentAngles[1]) / 50.0f, -maxVelocityPerStep, maxVelocityPerStep);

				currentAngles[2] +=
				    util::clamp(clampAngle(rollTarget - currentAngles[2]) / 50.0f, -maxVelocityPerStep, maxVelocityPerStep);

				Quaternion cameraOrientation {Quaternion::fromEuler(currentAngles[0], currentAngles[1], currentAngles[2])};
				Quaternion gimbalRotation {handleOrientation.conjugate() * cameraOrientation};

				auto rotationAngles {gimbalRotation.toEuler()};
				auto calculatedAngles {ikSolver.solve(rotationAngles)};

				if (softStartActive) {
					for (uint8_t i {0}; i < motorPositionRequest; ++i) {
						motorAngles[i] += clampAngle(calculatedAngles[i][0] - motorAngles[i])
						                / static_cast<float>(softStartDuration - (util::getTime() - softStartTime))
						                * (deltaTime * 2);

						if (std::isnan(calculatedAngles[i][0])) {
							continue;
						}

						motor::move(i + 1, util::mod(static_cast<int16_t>(motorAngles[i] * motorScalingFactor), fullRevolution));

						if (util::getTime() - softStartTime >= softStartDuration) {
							softStartActive = false;
						}
					}

					if (motorPositionRequest < 3 && util::getTime() - motorRequestTime > MOTOR_REQUEST_TIMEOUT) {
						motor::getVariable(++motorPositionRequest, MotorCommand::Variable::Position);
						motorRequestTime = util::getTime();
					}
				} else {
					for (uint8_t i {0}; i < 3; ++i) {
						motorAngles[i] = calculatedAngles[i][0];

						if (std::isnan(calculatedAngles[i][0])) {
							continue;
						}

						motor::move(i + 1, util::mod(static_cast<int16_t>(motorAngles[i] * motorScalingFactor), fullRevolution));
					}
				}

				while (!sensorReady && util::getTime() - startTime < deltaTime / 4) {
					__WFI();
				}
				sensorReady = false;

				auto elapsedTime {util::getTime() - startTime};
				if (elapsedTime < deltaTime) {
					util::sleep(deltaTime - elapsedTime);
				}
				break;
			}
			case (PowerMode::Idle):
			default: {
				if (!usb::isActive() && wokenByUSB) {
					powerMode = PowerMode::Sleep;
					uart::disable();
					host::disable();
					wokenByUSB = false;
				}

				util::sleep(deltaTime);
				break;
			}
			case (PowerMode::Sleep): {
				uart::enable();
				motor::sleep();
				if (usb::isActive()) {
					powerMode = PowerMode::Idle;
					uart::enable();
					wokenByUSB = true;
					break;
				}

				sleep();
				break;
			}
		}

		if (usb::isActive() && motorPassthrough && util::getTime() - motorPassthroughTime > USB_PASSTHROUGH_TIMEOUT) {
			uint8_t buf[1] {static_cast<uint8_t>(HostResponse::ResponseType::MotorPassthrough)};

			sendToHost(buf, sizeof(buf));
			motorPassthrough = false;
		}

		if (displayState == DisplayState::BatteryLevel) {
			uint8_t step = (util::getTime() - stateChangeTime) / VOLTAGE_DISPLAY_TIME;
			uint8_t leds = voltageBars / 2;


			if (step > 15) {
				displayState = DisplayState::GimbalMode;
				showMode();
				if (powerMode == PowerMode::Idle) {
					powerMode = PowerMode::Sleep;
				}
			} else if (step >= leds) {
				// The calculation steps + leds + 1 is just to ensure the same timing for all LEDs
				pwm::setBrightness(leds, voltageBars % 2 && (step + leds + 1) % 2 ? 0xffff : 0);
			} else {
				pwm::setBrightness(step, leds ? 0xffff : 0);
			}
		}

		if (buttonPressed && util::getTime() - eventTime > MAX_LONG_PRESS_TIME) {
			shortPresses = 0;
			showMode();
			if (powerMode == PowerMode::Idle) {
				powerMode = PowerMode::Sleep;
			}
		}

		if ((buttonPressed && util::getTime() - eventTime > MAX_SHORT_PRESS_TIME)
		    || (shortPresses && util::getTime() - eventTime > MAX_PRESS_WAIT_TIME)) {
			if (triggerAction()) {
				shortPresses = 0;
			}
		}

		WDT_REGS->WDT_CLEAR = WDT_CLEAR_CLEAR_KEY;
	}

	return 1;
}

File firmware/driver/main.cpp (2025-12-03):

#include "main.hpp"


static uint8_t            maxTorque {0};
constexpr static uint16_t halfRevolution {fullRevolution / 2};
constexpr static uint16_t quarterRevolution {fullRevolution / 4};

static MovementController movementController {};
static Mode               mode {Mode::Idle};  // Start in idle for UART compatibility
static uint32_t           lastTargetTime {0};
static uint32_t           lastCommandReceived {0};
static bool               poweredDown {mode == Mode::Sleep || mode == Mode::Idle};

static bool offsetAdjusted {false};

static uint16_t      currentAngle {0};
static float         prevDAngle {0.0f};
static bool          angleReady {false};
static LowPassFilter torqueFilter {1000, 2};

volatile static uint32_t hapticEnd {0};
volatile static uint16_t hapticPower {0};
static uint16_t          hapticDuration {0};
static bool              hapticDirection {false};

volatile static bool     wokenByPin {false};
volatile static uint32_t wakeTime {0};

struct TorqueLUT {
	uint16_t table[16];

	constexpr TorqueLUT():
	  table() {
		table[0] = 0;
		auto factor = (255.0f - idleTorque) / 15.0f;
		for (auto i = 1; i < 16; ++i) {
			table[i] = std::floor(factor * i + idleTorque);
		}
	}
};

constexpr static auto torqueLUT = TorqueLUT();

void powerDown() {
	if (poweredDown) {
		return;
	}
	PORT_REGS->GROUP[0].PORT_OUTCLR = 0x1 << 27u;
	bldc::removeTorque();
	angleReady = false;
	poweredDown = true;
}

void powerUp() {
	if (!poweredDown) {
		return;
	}
	PORT_REGS->GROUP[0].PORT_OUTSET = 0x1 << 27u;
	AS5600::init();
	poweredDown = false;
}

void enterSleep() {
	mode = Mode::Sleep;
	maxTorque = 0;
	powerDown();
	uart::disable();
	eic::enable();
}

// CAUTION: This function is called in an interrupt, no long-running operations allowed here!
void processWakeup() {
	uart::enable();
	mode = Mode::Idle;
	wokenByPin = true;
	wakeTime = util::getTime();
}

// CAUTION: This function is called in an interrupt, no long-running operations allowed here!
void processCommand(const uart::DefaultCallback::buffer_type& buffer) {
	if (!(buffer.buffer[0] & 0xf0)) {
		return;
	}

	uint8_t address = buffer.buffer[0] & 0x0f;
	if (address != deviceAddress && address != 0xf) {
		return;  // Command intended for another device
	}

	lastCommandReceived = util::getTime();

	switch (static_cast<Command::CommandType>(buffer.buffer[1] & 0x0f)) {  // Switch command type
		case (Command::CommandType::Sleep): {
			enterSleep();
			break;
		}
		case (Command::CommandType::Idle): {
			mode = Mode::Idle;
			maxTorque = 0;
			powerDown();
			break;
		}
		case (Command::CommandType::Wake): {
			mode = Mode::Idle;
			powerUp();
			lastTargetTime = 0;
			break;
		}
		case (Command::CommandType::Move): {
			mode = Mode::Drive;
			powerUp();
			auto     time {util::getTime()};
			uint16_t position = ((buffer.buffer[2] & 0x0f) << 8u) | buffer.buffer[3];
			if (nvm::options.flags.inverted) {
				position = fullRevolution - position;
			}
			movementController.extrapolate(time - lastTargetTime, position);
			if (offsetAdjusted) {
				offsetAdjusted = false;
				prevDAngle = 0.0f;
			}
			lastTargetTime = time;
			maxTorque = torqueLUT.table[buffer.buffer[2] >> 4u];
			break;
		}
		case (Command::CommandType::Tone): {
			bldc::tone((buffer.buffer[2] << 8u) | buffer.buffer[3]);
			break;
		}
		case (Command::CommandType::Haptic): {
			mode = Mode::Haptic;
			powerUp();
			hapticPower = torqueLUT.table[buffer.buffer[2] >> 4u];
			hapticEnd = util::getTime() + (((buffer.buffer[2] & 0x0f) << 8u) | buffer.buffer[3]);
			break;
		}
		case (Command::CommandType::AdjustOffset): {
			if (mode != Mode::Sleep && mode != Mode::Idle) {
				movementController.adjustOffset(currentAngle, ((buffer.buffer[2] & 0x0f) << 8u) | buffer.buffer[3]);
				uint16_t offset = movementController.getOffset();
				offsetAdjusted = true;
				nvm::edit(&nvm::options.zeroOffset, offset);
				nvm::write();
			}
			break;
		}
		case (Command::CommandType::GetVariable): {
			if (address == 0xf) {  // Get variable commands cannot be issued to all devices at once
				break;
			}
			switch (static_cast<Command::Variable>(buffer.buffer[2])) {  // Switch variable
				case (Command::Variable::Options): {
					auto response = ReturnVariableResponse(
					    deviceAddress,
					    buffer.buffer[1] >> 8u,
					    Command::Variable::Options,
					    static_cast<uint8_t>(0x04 | (nvm::options.flags.inverted << 1u) | !!nvm::options.polePairs)
					);
					uart::send(response.getBuffer(), response.getLength());
					break;
				}
				case (Command::Variable::Offset): {
					auto response = ReturnVariableResponse(
					    deviceAddress,
					    buffer.buffer[1] >> 8u,
					    Command::Variable::Offset,
					    static_cast<uint16_t>(movementController.getOffset())
					);
					uart::send(response.getBuffer(), response.getLength());
					break;
				}
				case (Command::Variable::Position): {
					uint16_t position = currentAngle - movementController.getOffset();
					if (nvm::options.flags.inverted) {
						position = fullRevolution - position;
					}
					auto response = ReturnVariableResponse(
					    deviceAddress,
					    buffer.buffer[1] >> 8u,
					    Command::Variable::Position,
					    static_cast<int16_t>(util::mod(static_cast<int32_t>(position), static_cast<int32_t>(fullRevolution)))
					);
					uart::send(response.getBuffer(), response.getLength());
					break;
				}
				default:
					break;
			}
			break;
		}
		case (Command::CommandType::SetVariable): {
			switch (static_cast<Command::Variable>(buffer.buffer[2])) {  // Switch variable
				case (Command::Variable::Options): {
					if (buffer.buffer[3] & 0x01) {  // Start calibration
						if (!nvm::options.polePairs) {
							mode = Mode::Calibrate;
							powerUp();
						}
					} else {  // Clear calibration
						nvm::edit(&nvm::options.polePairs, static_cast<uint8_t>(0));
					}
					auto flags = nvm::options.flags;

					flags.inverted = buffer.buffer[3] & 0x02;
					nvm::edit(&nvm::options.flags, flags);
					nvm::write();
					break;
				}
				case (Command::Variable::Offset): {
					movementController.setOffset((buffer.buffer[3] << 8u) | buffer.buffer[4]);
					uint16_t offset = movementController.getOffset();
					nvm::edit(&nvm::options.zeroOffset, offset);
					nvm::write();
					break;
				}
				default:
					break;
			}
			break;
		}
	}
}

float countsToRad(int16_t counts) {
	return static_cast<float>(counts) / fullRevolution * F_2_PI;
}

uint16_t measureAngle() {
	static uint16_t rawAngle;

	angleReady = false;
	auto startTime {util::getTime()};

	AS5600::getAngle([](bool success, const i2c::Transfer& transfer) {
		rawAngle = reinterpret_cast<const uint16_t*>(transfer.buf)[0];
		angleReady = true;
	});

	while (!angleReady && util::getTime() - startTime < 5) {
		__WFI();
	}

	return (currentAngle = __REV16(rawAngle));
}
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

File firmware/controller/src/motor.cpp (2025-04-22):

#include "motor.hpp"

void motor::sleep(uint8_t address) {
	auto command {
	  MotorCommand {0, address, MotorCommand::CommandType::Sleep, 0}
	};

	uart::send(command.getBuffer(), command.getLength());
}

void motor::idle(uint8_t address) {
	auto command {
	  MotorCommand {0, address, MotorCommand::CommandType::Idle, 0}
	};

	uart::send(command.getBuffer(), command.getLength());
}

void motor::wake(uint8_t address) {
	auto command {
	  MotorCommand {0, address, MotorCommand::CommandType::Wake, 0}
	};

	uart::send(command.getBuffer(), command.getLength());
}

void motor::move(uint8_t address, uint16_t position, uint8_t torque) {
	auto command {
	  MotorCommand {0, address, MotorCommand::CommandType::Move, 2}
	};
	auto& buf {command.getBuffer()};

	buf[2] = (torque << 4u) | (position >> 8u);
	buf[3] = position;

	uart::send(command.getBuffer(), command.getLength());
}

void motor::tone(uint8_t address, uint16_t frequency) {
	auto command {
	  MotorCommand {0, address, MotorCommand::CommandType::Tone, 2}
	};
	auto& buf {command.getBuffer()};

	buf[2] = frequency >> 8u;
	buf[3] = frequency;

	uart::send(command.getBuffer(), command.getLength());
}

void motor::haptic(uint8_t address, uint8_t intensity, uint16_t duration) {
	auto command {
	  MotorCommand {0, address, MotorCommand::CommandType::Haptic, 2}
	};
	auto& buf {command.getBuffer()};

	buf[2] = (intensity << 4u) | (duration >> 8u);
	buf[3] = duration;

	uart::send(command.getBuffer(), command.getLength());
}

void motor::adjustOffset(uint8_t address, uint16_t targetPosition) {
	auto command {
	  MotorCommand {0, address, MotorCommand::CommandType::AdjustOffset, 2}
	};
	auto& buf {command.getBuffer()};

	buf[2] = targetPosition >> 8u;
	buf[3] = targetPosition;

	uart::send(command.getBuffer(), command.getLength());
}

void motor::calibrate(uint8_t address, uint8_t mode) {
	auto command {
	  MotorCommand {0, address, MotorCommand::CommandType::Calibrate, 1}
	};
	auto& buf {command.getBuffer()};

	buf[2] = mode;

	uart::send(command.getBuffer(), command.getLength());
}

void motor::getVariable(uint8_t address, MotorCommand::Variable variable) {
	auto command {
	  MotorCommand {0, address, MotorCommand::CommandType::GetVariable, 1}
	};
	auto& buf {command.getBuffer()};

	buf[2] = static_cast<uint8_t>(variable);

	uart::send(command.getBuffer(), command.getLength());
}

void motor::send(const uint8_t* buf, uint8_t len, void (*cb)()) {
	uint8_t address = buf[0] & 0xf;

	if (!address) {  // Check destination address
		return;
	}

	uart::send(buf, len, cb);
}

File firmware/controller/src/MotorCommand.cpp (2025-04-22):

#include "MotorCommand.hpp"

MotorCommand::MotorCommand(uint8_t srcAddr, uint8_t destAddr, CommandType type, uint8_t dataLength) {
	this->_buffer[0] = ((dataLength + 1) << 4u) | destAddr;
	this->_buffer[1] = (srcAddr << 4u) | static_cast<uint8_t>(type);
}

MotorCommand::buffer_type& MotorCommand::getBuffer() {
	return this->_buffer;
}

MotorCommand::size_type MotorCommand::getLength() {
	return (this->_buffer[0] >> 4u) + 1;
}

const MotorCommand::buffer_type& MotorCommand::getBuffer() const {
	return this->_buffer;
}

const MotorCommand::size_type MotorCommand::getLength() const {
	return (this->_buffer[0] >> 4u) + 1;
}

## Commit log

2023-07-22 raised CPU and I2C frequency
2023-07-22 implemented motor power
2023-07-23 wip: dma endianness
2023-07-23 wip: applying torque
2023-07-24 added torque calculation
2023-07-24 implemented saving calibration
2023-07-24 implemented fast calibration
2023-07-28 fixed amount of applied power
    [main.cpp]
2023-07-29 optimized PWM generation
    switched PWM calculations to integers
2023-07-29 improved idle PWM
2023-07-31 added PWM capture
2023-07-31 wip: PID control
2023-08-05 tuned motor response
2023-10-10 DMA setup
2023-10-10 added UART input
2023-10-10 updated dependencies
    [pin_configurations.csv]
2023-11-07 UART protocol setup
    DMA setup
    removed template library
    added ring buffer
    removed dynamic memory allocation for communication/DMA
2023-11-08 UART data structure setup
2023-12-12 added control board project
2023-12-21 added battery measurement
2024-01-20 wip: DMA-less UART
2024-01-21 wip: uart transfers
2024-01-22 implemented interrupt-based UART
2024-01-22 added LED PWM
2024-01-23 added UART transfer queue
2024-01-29 added button interrupts
2024-01-29 added uart print
2024-01-30 improved uart types
2024-01-31 added multi-UART support
2024-01-31 integrated main and motor boards
2024-02-01 uart retarget setup
2024-02-05 fixed motor project config
2024-02-11 fixed uart race condition
    added task scheduler
2024-02-13 fixed torque direction
    added acceleration hysteresis
    [main.cpp]
2024-02-22 fixed tone period calculation
    added Node serial script
    [main.cpp]
2024-02-23 added calibration command
2024-02-23 added a motor class
2024-02-24 added motor enumeration
2024-02-29 added torque smoothing
2024-03-01 removed time-optimal control
    Turns out that sliding mode control with torque smoothing (aka. basic low-pass filter) is so unreasonably effective it can not only replace time-optimal control but actually control the motor better. With that said, it still causes oscillations without load so it'll have to be addressed separately
    [main.cpp]
2024-03-03 added target velocity compensation
2024-03-04 implemented toggling power
2024-03-05 added low pass filter and adjustable dead zone
2024-03-15 wip: target filtering
2024-03-15 added interpolation demo
    added precise Node delay
    fixed position modulo
    motor code cleanup
    [main.cpp]
2024-03-16 fixed target wraparound filtering
2024-04-09 implemented disabling motor
2024-04-18 adjusted filter frequency
    reduced number of wait states
2024-04-23 added Mahony filter
2024-04-23 mode switch improvements
2024-04-23 fixed Mahony filter
2024-04-23 added default options
    implemented multi-row writes
    temporarily removed target filter
2024-04-25 fixed quaternion difference calculation
    added initial interpolator value
    slowed down calibration
    [main.cpp]
2024-05-03 copied new NVM driver
2024-05-14 simplified options
    fixed main board nvm data
    [main.cpp]
2024-05-28 fixed pole calibration
2024-05-30 fixed pole calibration again
    [main.cpp]
2024-05-30 added motor position controls
2024-05-31 added yaw smoothing
    added more motor controls
2024-06-03 added remaining motor options
    improved exiting from sleep
2024-06-03 added calibration controls
2024-06-04 fixed exiting sleep mode
    [main.cpp]
2024-06-07 fixed yaw target wraparound
    [main.cpp]
2024-06-07 removed UART framing check
2024-06-09 updated UART protocol
    changed command length
    added timeouts
2024-06-09 improved calibration
    added calibration check step and timeouts
2024-06-14 wip: uart protocol
2024-06-17 rewrote control state machine
    fixed battery voltage range
    [main.cpp]
2024-06-17 added voltage animation
2024-06-21 regenerated MHC sources
    [pin_configurations.csv]
2024-06-27 wip: camera orientations
2024-06-28 joystick calibration setup
2024-07-01 reduced power consumption
    optimized control board power consumption
2024-07-02 improved control button logic
2024-07-02 added new camera mode
    fixed yaw offset sign
    [main.cpp]
2024-08-10 added extended ranges switch
2024-11-26 added calibration failure feedback and unwind
    [main.cpp]
2025-02-04 removed control UART
2025-02-04 added USB
    updated I2C driver
2025-02-06 implemented buttons and adc
2025-02-07 fixed uart error handling
    fixed battery voltage measurement
    [adc.cpp, main.cpp, uart.cpp]
2025-02-07 added control board angle correction
    fixed shutdown LED effect
    [main.cpp]
2025-02-13 wip: uart full-duplex mode
2025-02-18 fixed USB enumeration in sleep mode
    [main.cpp, uart.cpp]
2025-02-19 added the base for USB driver
2025-02-19 implemented motor command passthrough
2025-03-07 updated I2C pinout
2025-03-10 motor ultra low power
2025-03-10 driver low power fix
    [main.cpp]
2025-03-11 wip: control board low power
2025-03-24 fixed IMU init
2025-03-24 enabled ADC averaging
2025-03-24 added uart delay
2025-04-06 wip: low power
    implemented wake by interrupt
2025-04-11 added key error handling
    [motor.cpp, uart.cpp]
2025-04-11 wip: soft start fixes
    [i2c.cpp, main.cpp, uart.cpp]
2025-04-20 fixed sercom standby entry
    [LSM6DSO32.cpp, i2c.cpp, main.cpp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]
2025-04-22 added motor uart delay
2025-04-22 fixed motor request retries
    [MotorCommand.cpp, motor.cpp, uart.cpp]
2025-04-22 reduced power consumption
2025-04-30 reduced sensor latency
2025-04-30 fixed device info display
2025-05-01 implemented device view
2025-05-10 added voltage check before enabling
2025-05-11 refactored USB driver
2025-05-15 added option to invert motor direction
    [main.cpp]
2025-08-21 updated IK for correct angles
    [main.cpp]
2025-11-30 added high voltage and inverted options
    [main.cpp]
2025-12-02 implemented host uart
2025-12-03 clamped angles
2025-12-03 added device info
2025-12-03 fixed uart length
2025-12-03 added PCB designs
    [C1-B_Cu.gbr, C1-B_Mask.gbr, C1-B_Paste.gbr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]
2025-12-04 fixed numeric IK equation
    [NumericIKSolver.cpp]
2026-09-18 added 3d models
    [Bottom spacer.STEP, Gimbal.SLDASM, Handle spacer.STEP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]
